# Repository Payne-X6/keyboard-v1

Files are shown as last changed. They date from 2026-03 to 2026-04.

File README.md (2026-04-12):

# Custom keyboard

## Preview

You can find full [preview here](https://kicanvas.org/?repo=https%3A%2F%2Fgithub.com%2FPayne-X6%2Fkeyboard-v1%2Ftree%2Fmain%2Fpcb).

** In progress **

## Plate

- Foam PCB mute cotton for MX switches 
  https://www.amazon.co.uk/dp/B0BQQXK8NQ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

## Keycaps
### LPF

- 1 x 1 -    83x
- 2 x 1 -     1x
- 1 x 2 -     2x
- 1.25 x 1 - 10x
- 4.75 x 1 -  1x

### Flat

- 1 x 1 - 12x

## Switches

- Main 97x - Cherry MX xyz (tactile)
- Multimedia 12x - Kailh Choc V2 Low Profile Switch Brown (tactile)

## Sockets

- Kailh MX HotSwap - https://42keebs.eu/shop/parts/kailh-mx-hot-swap-sockets/

## Roller

- EVQWGD001
- THQWGD001

## Knob

## PCB
### MCU

- STM32F072CBTx

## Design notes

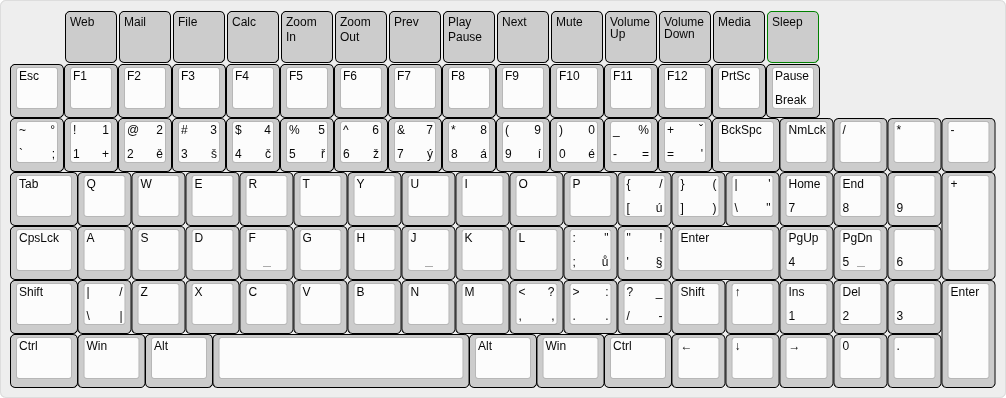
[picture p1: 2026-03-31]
keyboard-layout.png

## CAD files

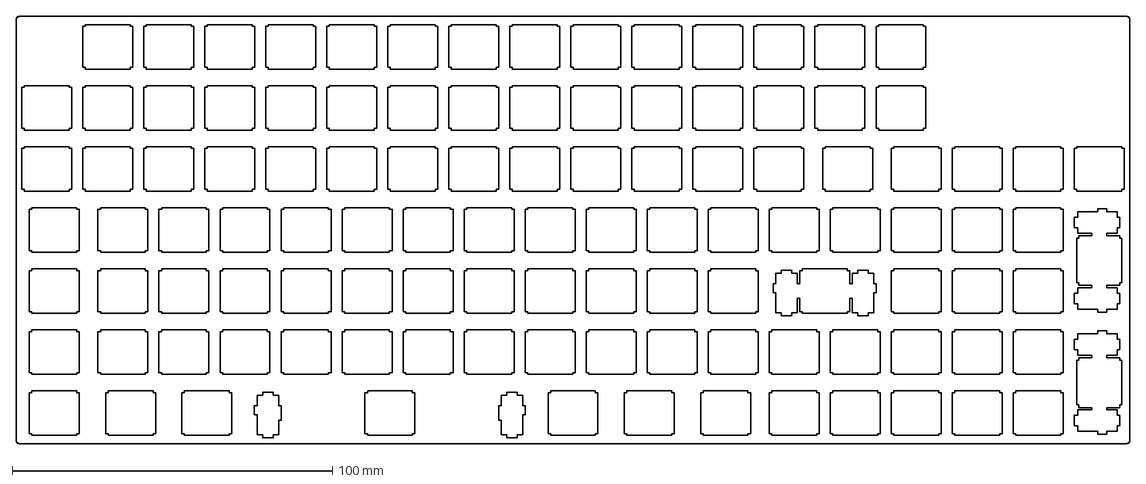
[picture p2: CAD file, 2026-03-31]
switch-plate.dxf
347.7 x 133.4 mm

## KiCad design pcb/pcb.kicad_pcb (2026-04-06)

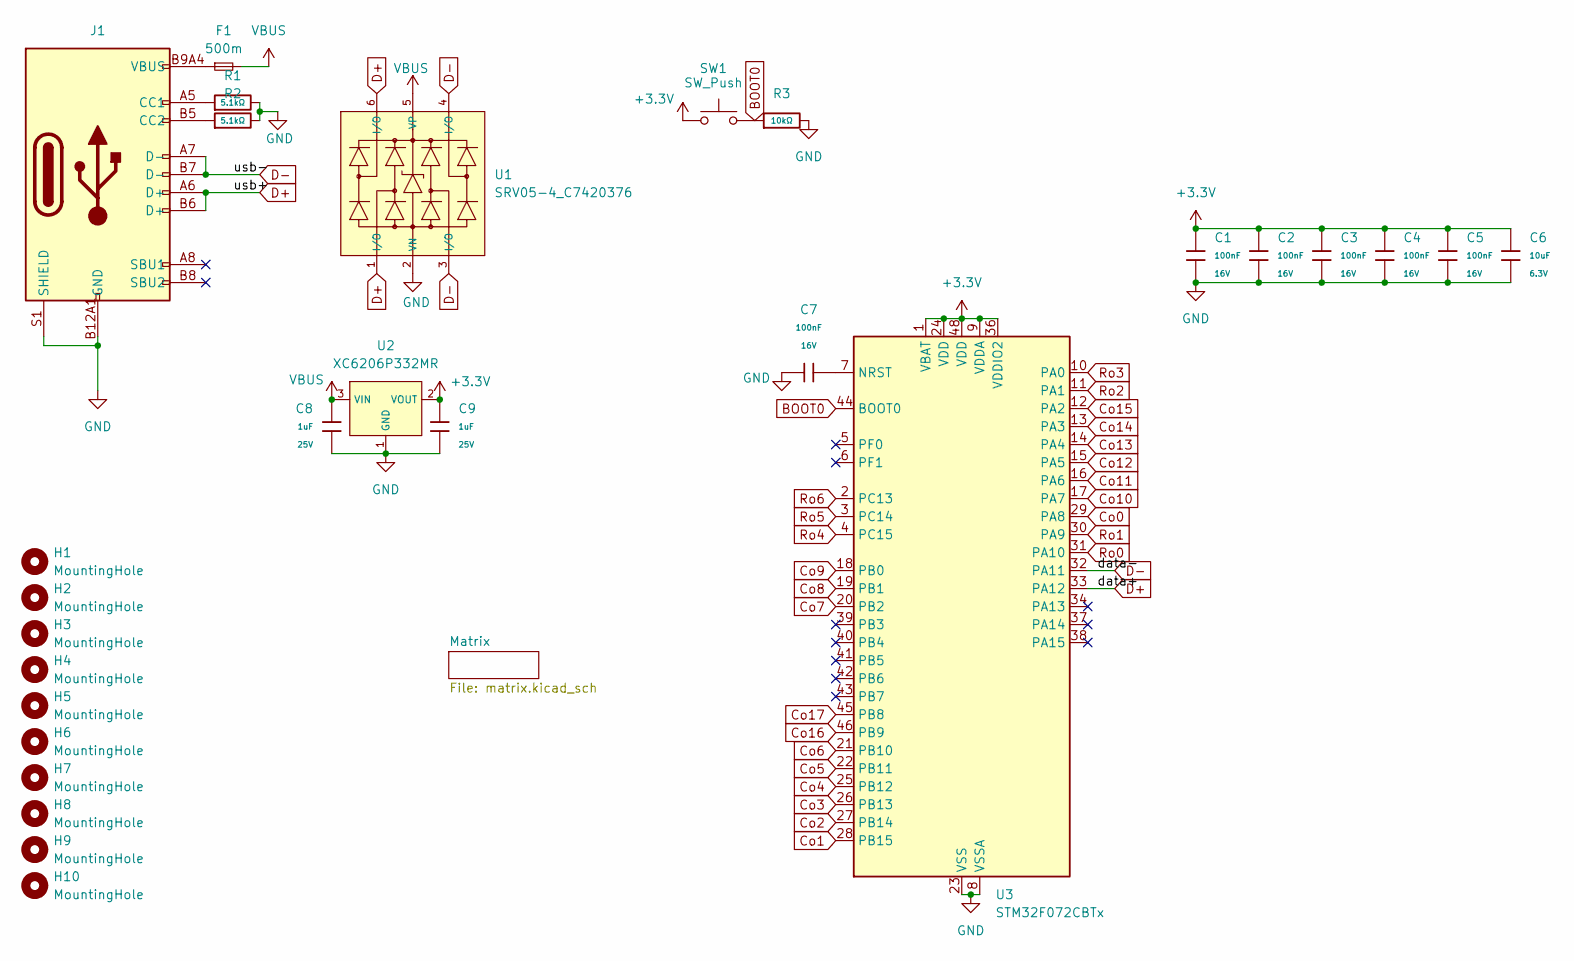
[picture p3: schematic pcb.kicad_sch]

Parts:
C1, C2, C3, C4, C5, C7: 100nF; C_0402; Voltage Rated 16V; Tolerance ±10%; Part CL05B104KO5NNNC; LCSC C1525
C6: 10uF; C_0402; Voltage Rated 6.3V; Tolerance ±20%; Part CL05A106MQ5NUNC; LCSC C15525
C8, C9: 1uF; C_0402; Voltage Rated 25V; Tolerance ±10%; Part CL05A105KA5NQNC; LCSC C52923
F1: 500m; Fuse_0603_1608Metric
H1, H2, H3, H4, H5, H6, H7, H8, H9, H10: MountingHole; MountingHole_2mm
J1: Connector, USB-TYPE-C-16P; TYPE-C-SMD_HX-TYPE-C-16PIN; LCSC C2927039
R1, R2: 5.1kΩ; R_0402; Overload Voltage (Max) 50V; Tolerance ±1%; Part 0402WGF5101TCE; LCSC C25905
R3: 10kΩ; R_0402; Overload Voltage (Max) 50V; Tolerance ±1%; Part 0402WGF1002TCE; LCSC C25744
SW1: SW_Push; SW_SPST_SKQG_WithStem; LCSC C115351
U1: SRV05-4_C7420376; SOT-23-6_L2.9-W1.6-P0.95-LS2.8-BL-1; Breakdown Voltage (Vbr) 6V; Clamping Voltage@Ipp 12.5V; Part SRV05-4; LCSC C7420376
U2: XC6206P332MR; SOT-23-3_L2.9-W1.6-P1.90-LS2.8-BR; Output Voltage 3.3V; Dropout Voltage 680mV@(100mA); Part XC6206P332MR-G; LCSC C5446
U3: STM32F072CBTx; LQFP-48_7x7mm_P0.5mm

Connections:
+3.3V: C1.2, C2.2, C3.2, C4.2, C5.2, C6.1, C9.1, SW1.1, U2.2 (VOUT), U3.1 (VBAT), U3.9 (VDDA), U3.24 (VDD), U3.36 (VDDIO2), U3.48 (VDD)
BOOT0: R3.1, SW1.2, U3.44 (BOOT0)
Co0: U3.29 (PA8); also elsewhere on the board
Co1: U3.28 (PB15); also elsewhere on the board
Co2: U3.27 (PB14); also elsewhere on the board
Co3: U3.26 (PB13); also elsewhere on the board
Co4: U3.25 (PB12); also elsewhere on the board
Co5: U3.22 (PB11); also elsewhere on the board
Co6: U3.21 (PB10); also elsewhere on the board
Co7: U3.20 (PB2); also elsewhere on the board
Co8: U3.19 (PB1); also elsewhere on the board
Co9: U3.18 (PB0); also elsewhere on the board
Co10: U3.17 (PA7); also elsewhere on the board
Co11: U3.16 (PA6); also elsewhere on the board
Co12: U3.15 (PA5); also elsewhere on the board
Co13: U3.14 (PA4); also elsewhere on the board
Co14: U3.13 (PA3); also elsewhere on the board
Co15: U3.12 (PA2); also elsewhere on the board
Co16: U3.46 (PB9); also elsewhere on the board
Co17: U3.45 (PB8); also elsewhere on the board
D+: J1.A6 (D+), J1.B6 (D+), U1.1 (I/O), U1.6 (I/O), U3.33 (PA12)
D-: J1.A7 (D-), J1.B7 (D-), U1.3 (I/O), U1.4 (I/O), U3.32 (PA11)
GND: C1.1, C2.1, C3.1, C4.1, C5.1, C6.2, C7.1, C8.2, C9.2, J1.A12B1 (GND), J1.B12A1 (GND), J1.S1 (SHIELD), R1.2, R2.2, R3.2, U1.2 (VN), U2.1 (GND), U3.8 (VSSA), U3.23 (VSS), U3.35 (VSS), U3.47 (VSS)
unnamed: F1.1, J1.A9B4 (VBUS), J1.B9A4 (VBUS)
unnamed: J1.A5 (CC1), R1.1
unnamed: J1.B5 (CC2), R2.1
unnamed: C7.2, U3.7 (NRST)
Ro0: U3.31 (PA10); also elsewhere on the board
Ro1: U3.30 (PA9); also elsewhere on the board
Ro2: U3.11 (PA1); also elsewhere on the board
Ro3: U3.10 (PA0); also elsewhere on the board
Ro4: U3.4 (PC15); also elsewhere on the board
Ro5: U3.3 (PC14); also elsewhere on the board
Ro6: U3.2 (PC13); also elsewhere on the board
VBUS: C8.1, F1.2, U1.5 (VP), U2.3 (VIN)

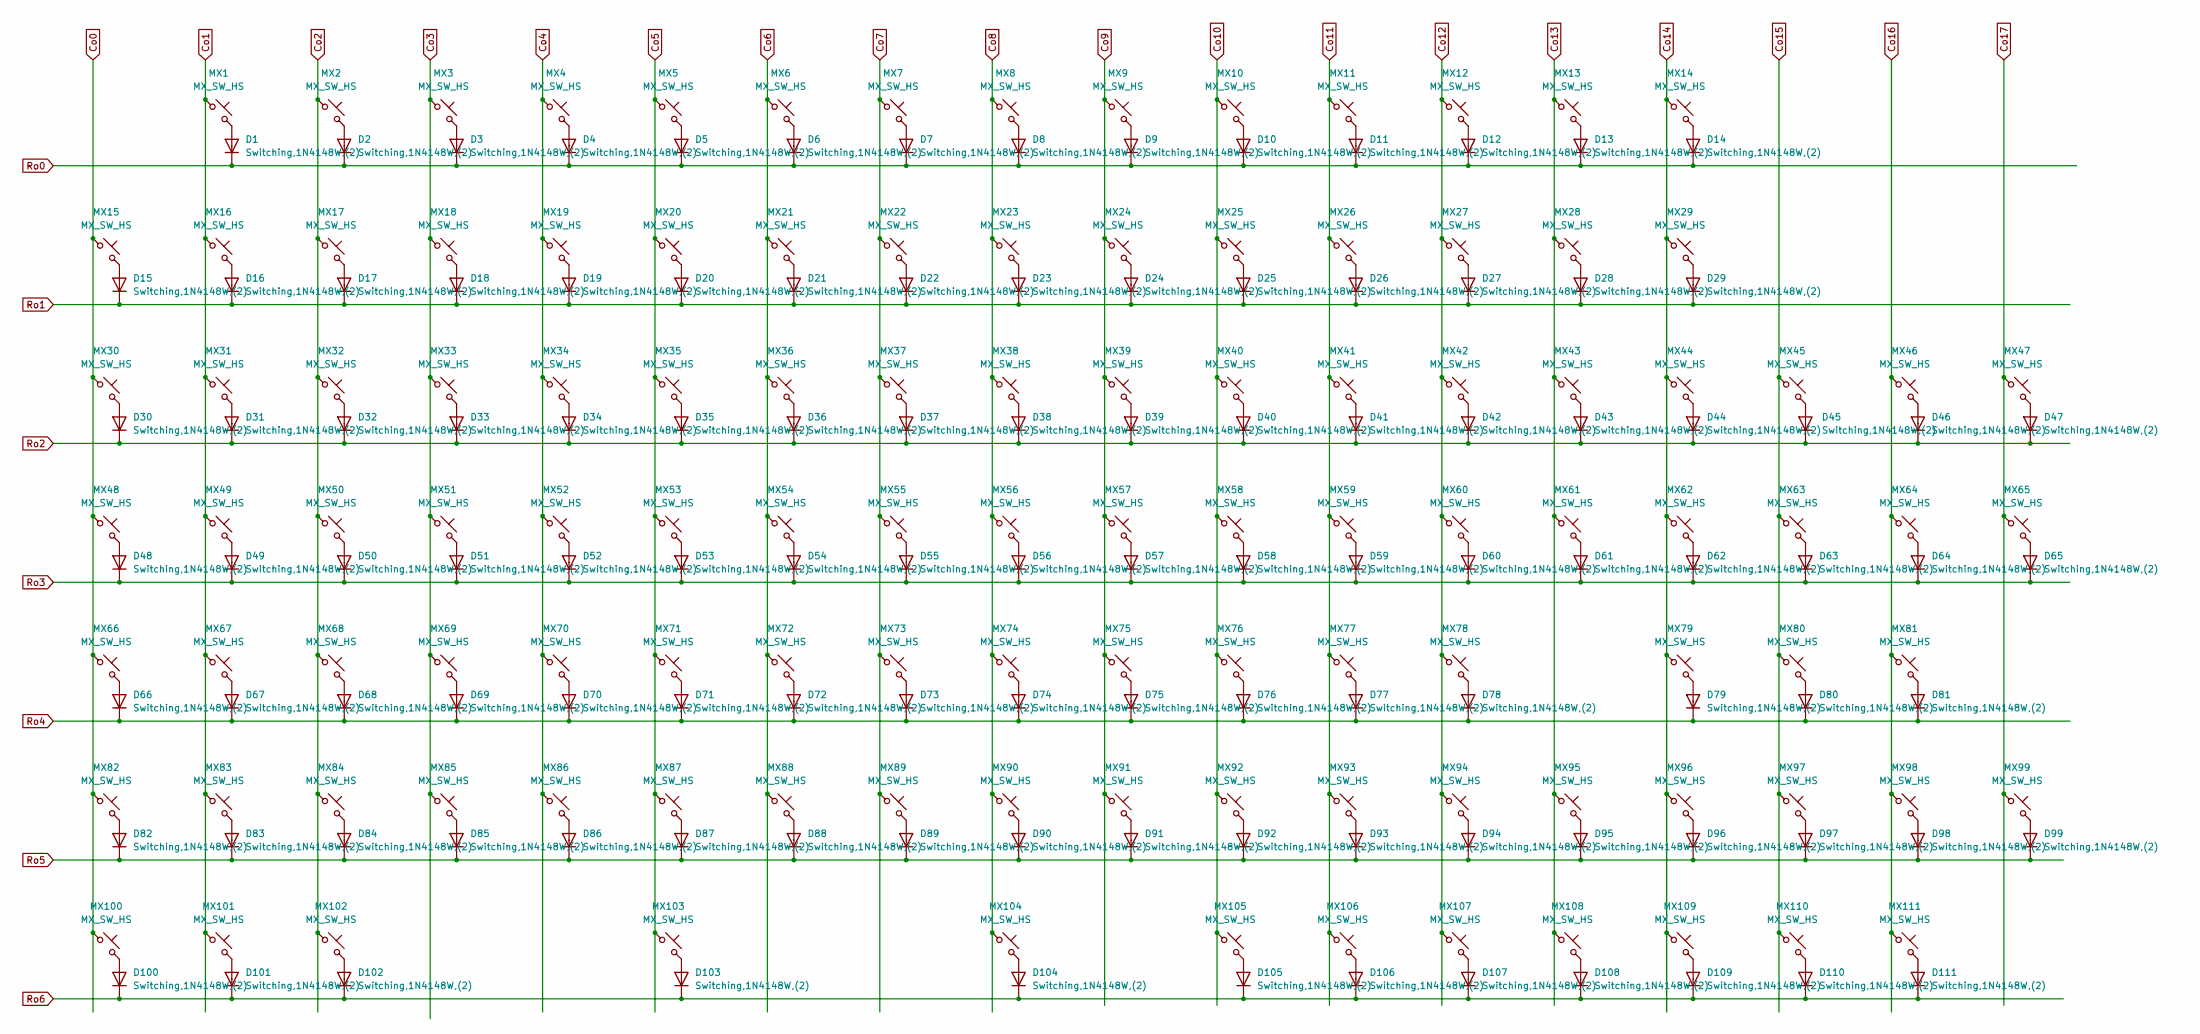
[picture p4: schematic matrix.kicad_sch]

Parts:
D1, D2, D3, D4, D5, D6, D7, D8, D9, D10, D11, D12, D13, D14, D15, D16, D17, D18, D19, D20, D21, D22, D23, D24, D25, D26, D27, D28, D29, D30, D31, D32, D33, D34, D35, D36, D37, D38, D39, D40, D41, D42, D43, D44, D45, D46, D47, D48, D49, D50, D51, D52, D53, D54, D55, D56, D57, D58, D59, D60, D61, D62, D63, D64, D65, D66, D67, D68, D69, D70, D71, D72, D73, D74, D75, D76, D77, D78, D79, D80, D81, D82, D83, D84, D85, D86, D87, D88, D89, D90, D91, D92, D93, D94, D95, D96, D97, D98, D99, D100, D101, D102, D103, D104, D105, D106, D107, D108, D109, D110, D111: Switching,1N4148W,(2); D_SOD-123
MX1, MX2, MX3, MX4, MX5, MX6, MX7, MX8, MX9, MX10, MX11, MX12, MX13, MX14, MX15, MX16, MX17, MX18, MX19, MX20, MX21, MX22, MX23, MX24, MX25, MX26, MX27, MX28, MX29, MX30, MX31, MX32, MX33, MX34, MX35, MX36, MX37, MX38, MX39, MX40, MX41, MX42, MX44, MX45, MX46, MX47, MX49, MX50, MX51, MX52, MX53, MX54, MX55, MX56, MX57, MX58, MX59, MX60, MX61, MX62, MX63, MX64, MX65, MX67, MX68, MX69, MX70, MX71, MX72, MX73, MX74, MX75, MX76, MX77, MX78, MX79, MX80, MX81, MX83, MX84, MX85, MX86, MX87, MX88, MX89, MX90, MX91, MX92, MX93, MX94, MX95, MX96, MX97, MX98, MX99, MX103, MX107, MX108, MX109, MX110, MX111: MX_SW_HS; SW_MX_HS_CPG151101S11_1u
MX43, MX48, MX66, MX82, MX100, MX101, MX102, MX104, MX105, MX106: MX_SW_HS; SW_MX_HS_CPG151101S11_1.25u

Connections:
Co0: MX15.1, MX30.1, MX48.1, MX66.1, MX82.1, MX100.1; also elsewhere on the board
Co1: MX1.1, MX16.1, MX31.1, MX49.1, MX67.1, MX83.1, MX101.1; also elsewhere on the board
Co2: MX2.1, MX17.1, MX32.1, MX50.1, MX68.1, MX84.1, MX102.1; also elsewhere on the board
Co3: MX3.1, MX18.1, MX33.1, MX51.1, MX69.1, MX85.1; also elsewhere on the board
Co4: MX4.1, MX19.1, MX34.1, MX52.1, MX70.1, MX86.1; also elsewhere on the board
Co5: MX5.1, MX20.1, MX35.1, MX53.1, MX71.1, MX87.1, MX103.1; also elsewhere on the board
Co6: MX6.1, MX21.1, MX36.1, MX54.1, MX72.1, MX88.1; also elsewhere on the board
Co7: MX7.1, MX22.1, MX37.1, MX55.1, MX73.1, MX89.1; also elsewhere on the board
Co8: MX8.1, MX23.1, MX38.1, MX56.1, MX74.1, MX90.1, MX104.1; also elsewhere on the board
Co9: MX9.1, MX24.1, MX39.1, MX57.1, MX75.1, MX91.1; also elsewhere on the board
Co10: MX10.1, MX25.1, MX40.1, MX58.1, MX76.1, MX92.1, MX105.1; also elsewhere on the board
Co11: MX11.1, MX26.1, MX41.1, MX59.1, MX77.1, MX93.1, MX106.1; also elsewhere on the board
Co12: MX12.1, MX27.1, MX42.1, MX60.1, MX78.1, MX94.1, MX107.1; also elsewhere on the board
Co13: MX13.1, MX28.1, MX43.1, MX61.1, MX95.1, MX108.1; also elsewhere on the board
Co14: MX14.1, MX29.1, MX44.1, MX62.1, MX79.1, MX96.1, MX109.1; also elsewhere on the board
Co15: MX45.1, MX63.1, MX80.1, MX97.1, MX110.1; also elsewhere on the board
Co16: MX46.1, MX64.1, MX81.1, MX98.1, MX111.1; also elsewhere on the board
Co17: MX47.1, MX65.1, MX99.1; also elsewhere on the board
unnamed: D1.2, MX1.2
unnamed: D2.2, MX2.2
unnamed: D3.2, MX3.2
unnamed: D4.2, MX4.2
unnamed: D5.2, MX5.2
unnamed: D6.2, MX6.2
unnamed: D7.2, MX7.2
unnamed: D8.2, MX8.2
unnamed: D9.2, MX9.2
unnamed: D10.2, MX10.2
unnamed: D11.2, MX11.2
unnamed: D12.2, MX12.2
unnamed: D13.2, MX13.2
unnamed: D14.2, MX14.2
unnamed: D15.2, MX15.2
unnamed: D16.2, MX16.2
unnamed: D17.2, MX17.2
unnamed: D18.2, MX18.2
unnamed: D19.2, MX19.2
unnamed: D20.2, MX20.2
unnamed: D21.2, MX21.2
unnamed: D22.2, MX22.2
unnamed: D23.2, MX23.2
unnamed: D24.2, MX24.2
unnamed: D25.2, MX25.2
unnamed: D26.2, MX26.2
unnamed: D27.2, MX27.2
unnamed: D28.2, MX28.2
unnamed: D29.2, MX29.2
unnamed: D30.2, MX30.2
unnamed: D31.2, MX31.2
unnamed: D32.2, MX32.2
unnamed: D33.2, MX33.2
unnamed: D34.2, MX34.2
unnamed: D35.2, MX35.2
unnamed: D36.2, MX36.2
unnamed: D37.2, MX37.2
unnamed: D38.2, MX38.2
unnamed: D39.2, MX39.2
unnamed: D40.2, MX40.2
unnamed: D41.2, MX41.2
unnamed: D42.2, MX42.2
unnamed: D43.2, MX43.2
unnamed: D44.2, MX44.2
unnamed: D45.2, MX45.2
unnamed: D46.2, MX46.2
unnamed: D47.2, MX47.2
unnamed: D48.2, MX48.2
unnamed: D49.2, MX49.2
unnamed: D50.2, MX50.2
unnamed: D51.2, MX51.2
unnamed: D52.2, MX52.2
unnamed: D53.2, MX53.2
unnamed: D54.2, MX54.2
unnamed: D55.2, MX55.2
unnamed: D56.2, MX56.2
unnamed: D57.2, MX57.2
unnamed: D58.2, MX58.2
unnamed: D59.2, MX59.2
unnamed: D60.2, MX60.2
unnamed: D61.2, MX61.2
unnamed: D62.2, MX62.2
unnamed: D63.2, MX63.2
unnamed: D64.2, MX64.2
unnamed: D65.2, MX65.2
unnamed: D66.2, MX66.2
unnamed: D67.2, MX67.2
unnamed: D68.2, MX68.2
unnamed: D69.2, MX69.2
unnamed: D70.2, MX70.2
unnamed: D71.2, MX71.2
unnamed: D72.2, MX72.2
unnamed: D73.2, MX73.2
unnamed: D74.2, MX74.2
unnamed: D75.2, MX75.2
unnamed: D76.2, MX76.2
unnamed: D77.2, MX77.2
unnamed: D78.2, MX78.2
unnamed: D79.2, MX79.2
unnamed: D80.2, MX80.2
unnamed: D81.2, MX81.2
unnamed: D82.2, MX82.2
unnamed: D83.2, MX83.2
unnamed: D84.2, MX84.2
unnamed: D85.2, MX85.2
unnamed: D86.2, MX86.2
unnamed: D87.2, MX87.2
unnamed: D88.2, MX88.2
unnamed: D89.2, MX89.2
unnamed: D90.2, MX90.2
unnamed: D91.2, MX91.2
unnamed: D92.2, MX92.2
unnamed: D93.2, MX93.2
unnamed: D94.2, MX94.2
unnamed: D95.2, MX95.2
unnamed: D96.2, MX96.2
unnamed: D97.2, MX97.2
unnamed: D98.2, MX98.2
unnamed: D99.2, MX99.2
unnamed: D100.2, MX100.2
unnamed: D101.2, MX101.2
unnamed: D102.2, MX102.2
unnamed: D103.2, MX103.2
unnamed: D104.2, MX104.2
unnamed: D105.2, MX105.2
unnamed: D106.2, MX106.2
unnamed: D107.2, MX107.2
unnamed: D108.2, MX108.2
unnamed: D109.2, MX109.2
unnamed: D110.2, MX110.2
unnamed: D111.2, MX111.2
Ro0: D1.1, D2.1, D3.1, D4.1, D5.1, D6.1, D7.1, D8.1, D9.1, D10.1, D11.1, D12.1, D13.1, D14.1; also elsewhere on the board
Ro1: D15.1, D16.1, D17.1, D18.1, D19.1, D20.1, D21.1, D22.1, D23.1, D24.1, D25.1, D26.1, D27.1, D28.1, D29.1; also elsewhere on the board
Ro2: D30.1, D31.1, D32.1, D33.1, D34.1, D35.1, D36.1, D37.1, D38.1, D39.1, D40.1, D41.1, D42.1, D43.1, D44.1, D45.1, D46.1, D47.1; also elsewhere on the board
Ro3: D48.1, D49.1, D50.1, D51.1, D52.1, D53.1, D54.1, D55.1, D56.1, D57.1, D58.1, D59.1, D60.1, D61.1, D62.1, D63.1, D64.1, D65.1; also elsewhere on the board
Ro4: D66.1, D67.1, D68.1, D69.1, D70.1, D71.1, D72.1, D73.1, D74.1, D75.1, D76.1, D77.1, D78.1, D79.1, D80.1, D81.1; also elsewhere on the board
Ro5: D82.1, D83.1, D84.1, D85.1, D86.1, D87.1, D88.1, D89.1, D90.1, D91.1, D92.1, D93.1, D94.1, D95.1, D96.1, D97.1, D98.1, D99.1; also elsewhere on the board
Ro6: D100.1, D101.1, D102.1, D103.1, D104.1, D105.1, D106.1, D107.1, D108.1, D109.1, D110.1, D111.1; also elsewhere on the board

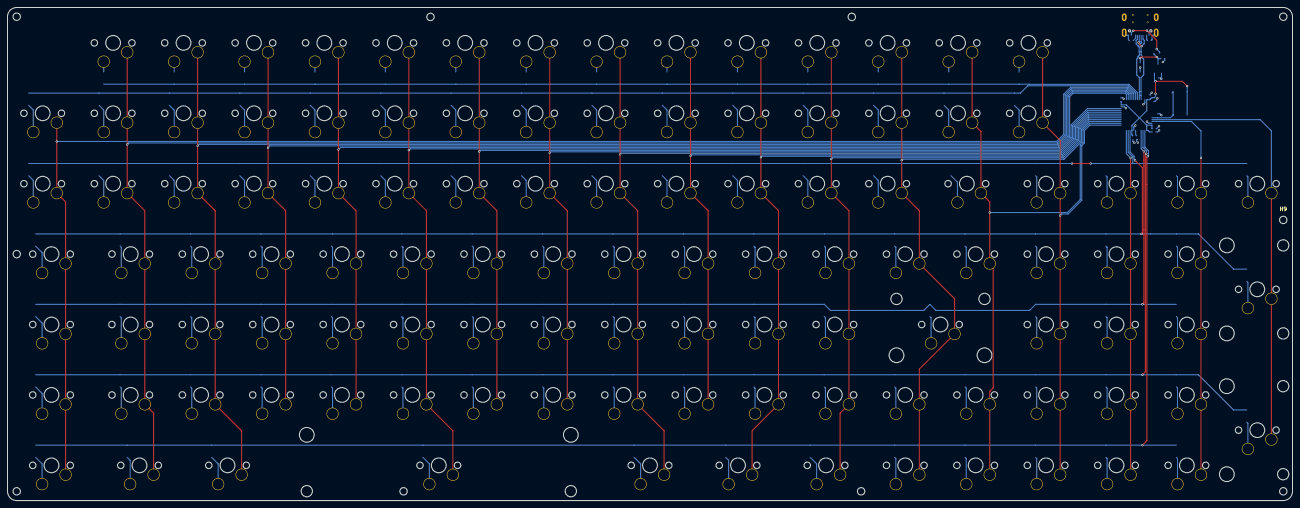
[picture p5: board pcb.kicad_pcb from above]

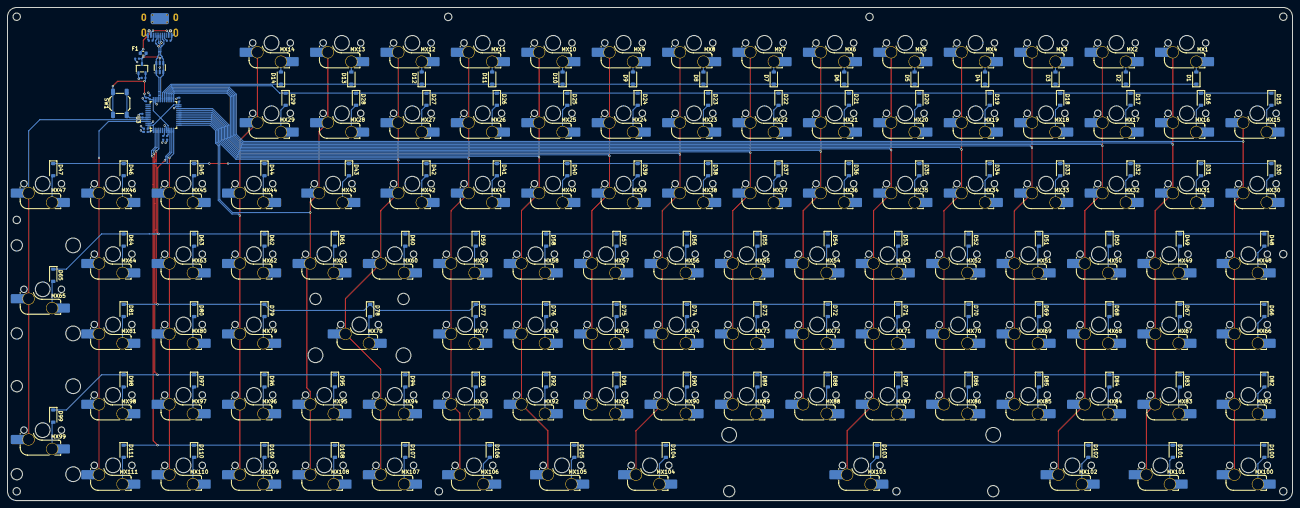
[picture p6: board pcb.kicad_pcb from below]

Board: 2 copper layers, 347.7 x 133.4 mm, 250 parts (240 on the bottom side), 146 nets.

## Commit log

2026-03-31 New (#1)
    * rearange repository
    * Readme
    [matrix.kicad_sch, pcb.kicad_pcb, pcb.kicad_sch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]
2026-03-31 change MCU to STM32F0
    [pcb.kicad_pcb, pcb.kicad_sch]
2026-04-01 ESD protection
    [pcb.kicad_pcb, pcb.kicad_sch]
2026-04-02 Connecting MCU
    [pcb.kicad_pcb, pcb.kicad_sch]
2026-04-03 Connects all components on the PCB
    [pcb.kicad_pcb, pcb.kicad_sch]
2026-04-04 Mouting holes
    [pcb.kicad_pcb]
2026-04-04 200 more connections to go
    [pcb.kicad_pcb]
2026-04-04 100 more connections to go
    [pcb.kicad_pcb]
2026-04-04 Matrix ready
    [pcb.kicad_pcb, pcb.kicad_sch]
2026-04-05 Change generic diodes to SOD-123
    50% done
    [matrix.kicad_sch, pcb.kicad_pcb, pcb.kicad_sch]
2026-04-05 finished diodes and finished top MCU datalines
    [pcb.kicad_pcb, pcb.kicad_sch]
2026-04-05 Add some LSCPCB footprints
    [pcb.kicad_pcb, pcb.kicad_sch]
2026-04-06 Replace some more with LSCPCB library
    [matrix.kicad_sch, pcb.kicad_pcb, pcb.kicad_sch]
2026-04-06 matrix connected
    [pcb.kicad_pcb, pcb.kicad_sch]
2026-04-06 fix mouting holes
    [pcb.kicad_sch]
2026-04-06 jlcpcb USB-C
    [pcb.kicad_pcb, pcb.kicad_sch]
2026-04-07 Before production
    [pcb.kicad_sch]
